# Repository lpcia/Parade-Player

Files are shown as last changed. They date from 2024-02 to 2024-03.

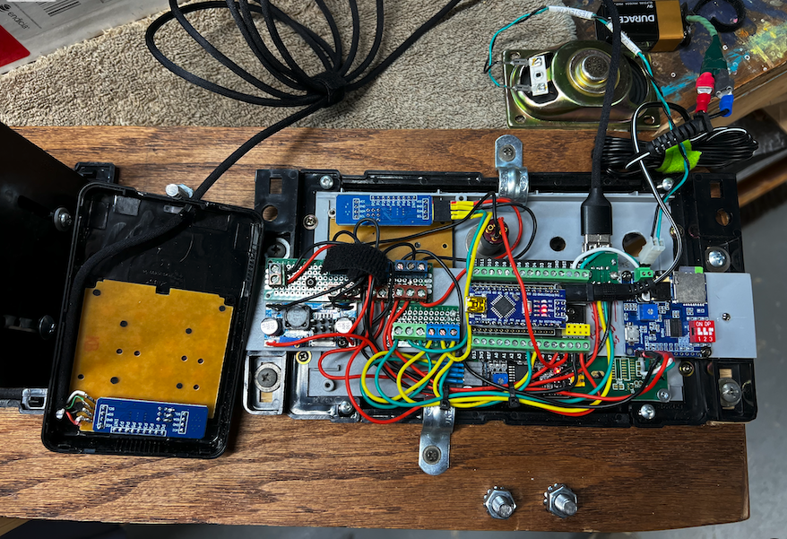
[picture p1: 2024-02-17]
Media/Version 2 almost complete (Note test speaker and Battery).png

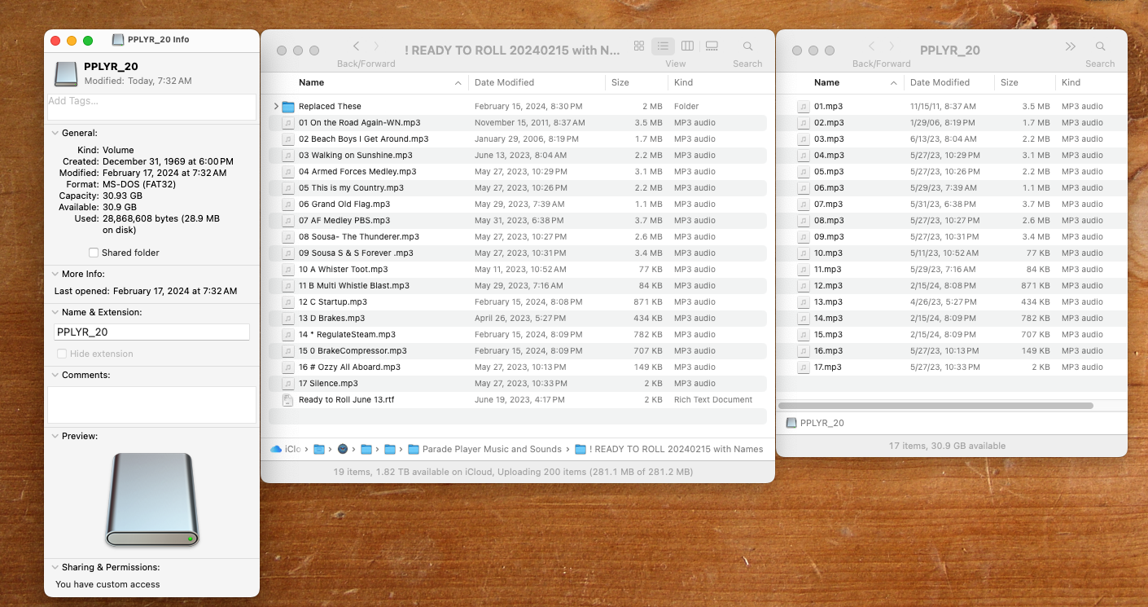
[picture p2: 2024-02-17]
Sound File Naming Example.png

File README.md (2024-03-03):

# Parade Player
Arduino based DY-???? / DYPlayer MP3 Player with I2CKeyPad input, and a HD44780 LCD Display.  Designed for parade floats.
This version works with an automobile head-unit using just the aux port.  Of course we have large weatherproof speakers on our "float".  We didn't need an external amplifier in our case.  Those speakers are loud enough!

## Concept

This is an Arduino Project that lets people interact with audio (in this case), lighting, and anamatronics.

## Background
I belong to a G Scale model railroad club that sets up large displays at train shows and local civic events such as a Christmas display at our city museum.  I wanted to make a display / decoration of an old service station that visitors could interact with to play sounds, start animatronics, or turn on lights by pressing a button on a (wired) remote keypad.

I had been toying around with various keypads / mp3 player circuit boards, etc. when a veterans group I belong to finally decided to reactivate an old self-propelled locomotive parade float that had been sitting in a garage for 15 years.  The vehicle is a modified 1938 Nash Lafayette built at the Nash plant here in Kenosha, WI.  In order to modernize her, We had to remove 200+ pounds of compressors, tanks, air lines and 80 years of old wiring and automotive electronics from the 1970's.  Instead of using air, I decided to use electronics to play music and sounds and re-engineered my idea into this Parade Locomotive Player.

## Operations
The MP3 Player is powered by the vehicle's 12 volt battery via a buck converter.  It is connected to the vehicle radio/ head-unit via the aux port.  In my case, I can play CD's and the Radio through the fender mounted speakers using the radio's controls.  Volume is also controlled by the radio.  

To play sounds, simply push a button on the keypad, and i'n my case a wired remote.  We added a remote because the driver cannot see the right front because of bells and smoke stacks, so a co-enginneer is required.  Even for them, pressing one of the buttons on the unit took their eyes off the road, so the remote was added.  It is simply a second keyboard / PCF8574 Remote 8-Bit I/O Expander for I2C Bus.  I wired it with a ten foot, tough old USB cable and used the existing USB connector (Probably a bad idea, but it works!).  Oddly the wired remote works without changes to the code.  I thought I was going to have to change the I2C address, but it just worked.

## Etcetera
Check out the pictures of our locomotive in the Media folder or visit https://sewivets.org/Voiture410/ 

> If you would like to donate to this project or our Nurses Training Fund, please see details on the website.

Thanks to 
1. Chris Snijde for the awesome work he did to make using generic DY players easy to use.
    - https://github.com/SnijderC/dyplayer
3. Gavin Lyons for is work with HD44780_LCD_PCF8574.h
    - https://github.com/gavinlyonsrepo/HD44780_LCD_PCF8574
4. And of course Adafruit!
    - https://www.adafruit.com

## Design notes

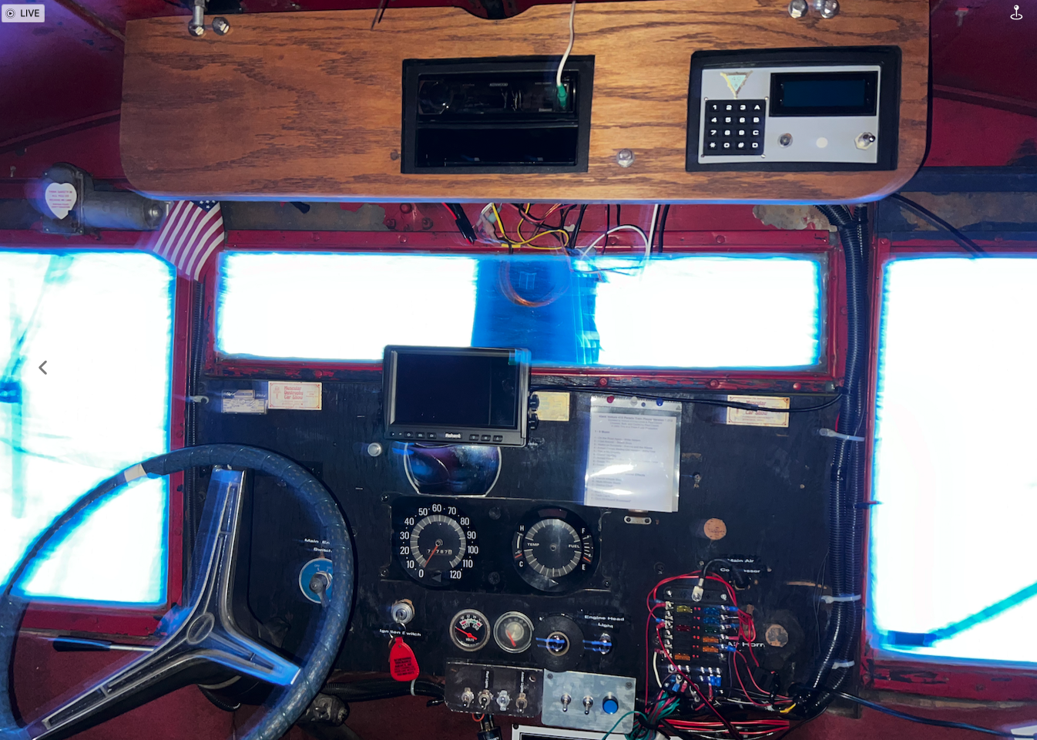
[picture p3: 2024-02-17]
Media/Cab_Nearly_Complete.png

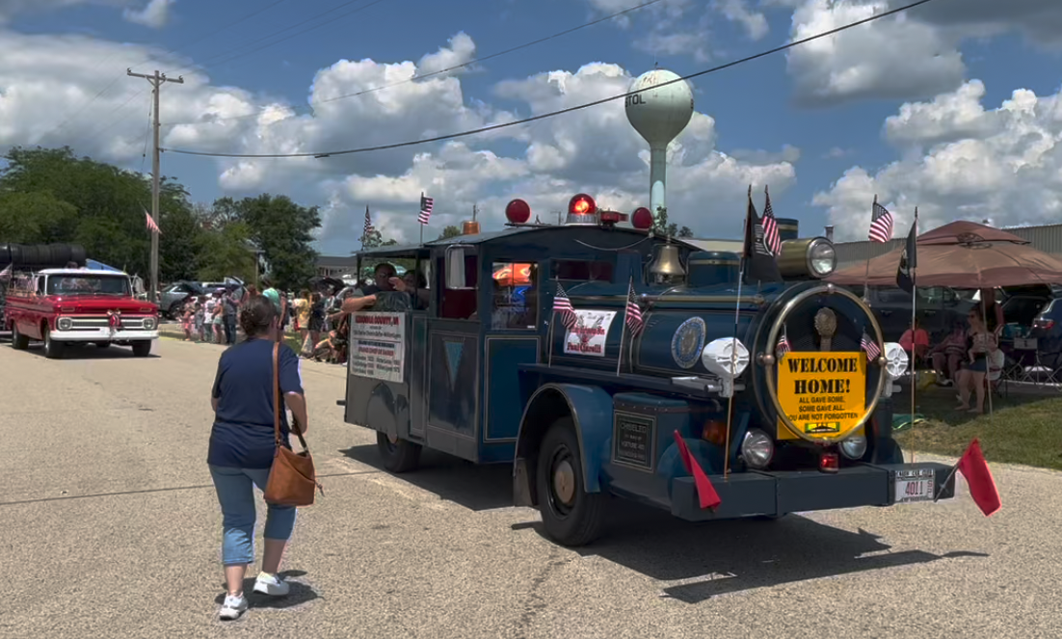
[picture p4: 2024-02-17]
Media/InTheParade.png

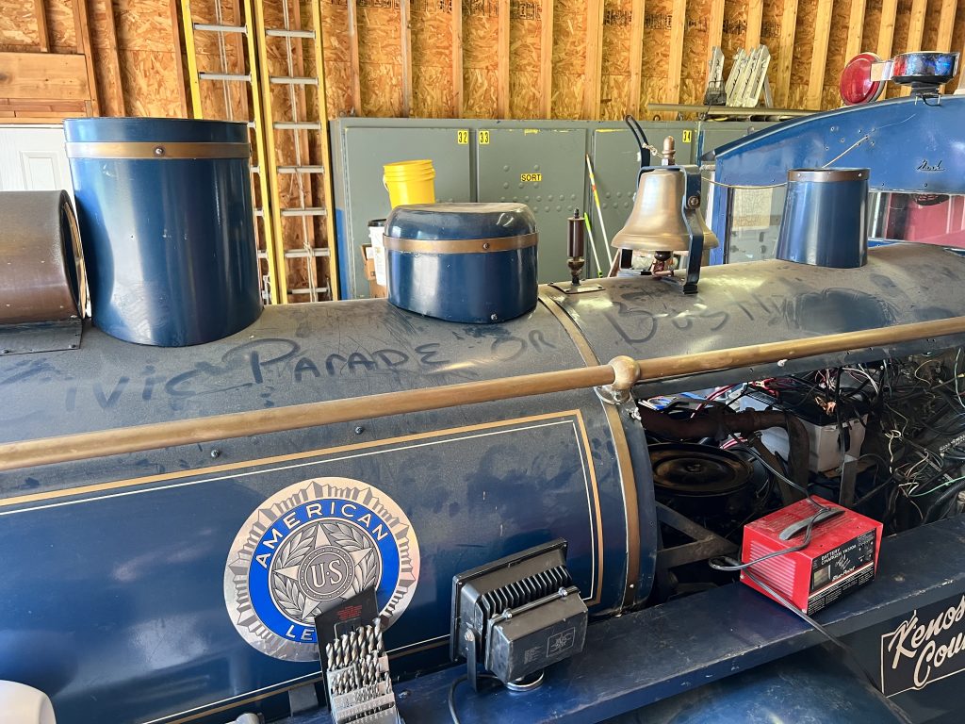
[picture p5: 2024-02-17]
Media/CivicParadeorBust.jpeg

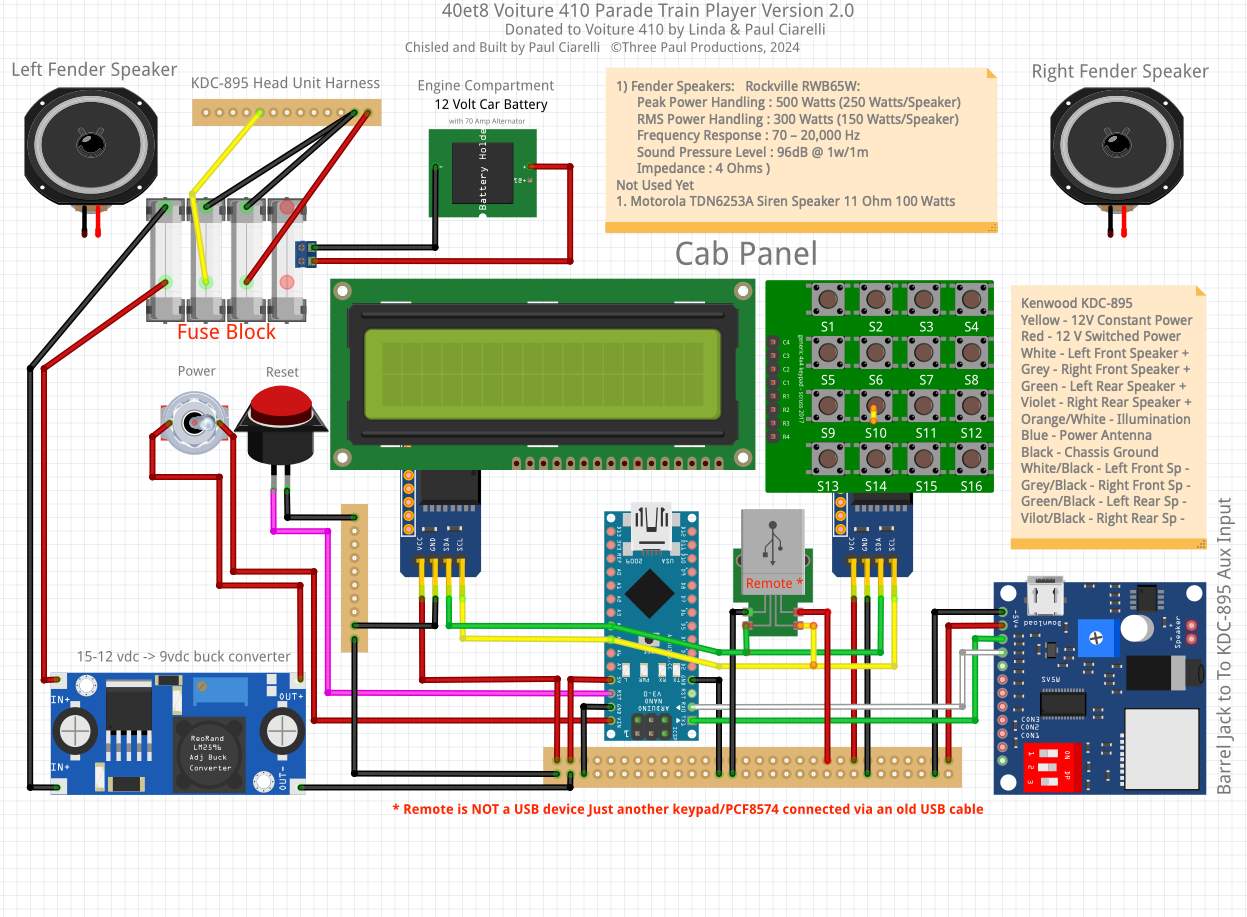
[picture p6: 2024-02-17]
Fritzing_Screenshot.png

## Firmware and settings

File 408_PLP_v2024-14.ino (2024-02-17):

/* 40et8 Voiture 410 Parade Train Player Version 2.2
   Donated to Voiture 410 by Linda & Paul Ciarelli
   Chiseled and Built by Paul Ciarelli   
   © 2003 This is a Three Pauls Production

Special Thanks to:
  Jim Holter for donating wiring / electrical parts.
  Tim Green & the "Green Machine" for helping with design and installation

See Documentation Tab for more information

Functions:  
  Print to LCD: 
  void blurt2Display(int8_t x, char *displayLine1, char *displayLine2, int delayTime) {}
    LCD Line 0 - 4
    Lines 1 - 4 as strings
    set a delay if needed
  Play a sound file:  
    void playSelection(int selNumber, int selDuration) {  
    Selection # and length in seconds -- delay required to stop some chop.
*/

// Preamble
// Section: Included library 
#include <Arduino.h>
#include "DYPlayerArduino.h"      // DY-SV5W
#include "HD44780_LCD_PCF8574.h"  // Thanks Gavin Lyons!  This was the one.
#include "I2CKeyPad.h"            // 4x4 Telephone Keypad

// Section: Globals / Initialization
// Init MP3 Player
  DY::Player player;  // Initialise the player, it defaults to using Serial.

// Init Display
  HD44780LCD myLCD( 4, 20, 0x27, &Wire); // instantiate an object
//                     12345678901234567890  
  char lcdLine1[21] = "40&8 V410 P. Player "; // Lines 1 and 2 will normally be static,
  char lcdLine2[21] = "Press Reset to Stop "; 
  char lcdLine3[21]; // Lines 3 and 4 will show current variables such as song selected.
  char lcdLine4[21]; 
  uint32_t selDelay = 300;
  uint32_t normDelay = 4000;

// Init keypad
  const uint8_t KEYPAD_ADDRESS = 0x20;
  I2CKeyPad keyPad(KEYPAD_ADDRESS);
  uint32_t start, stop;
  uint32_t lastKeyPressed = 0;
  char iChar = " ";
// Section: Function Prototypes

// Section: Setup
// ====== ========= ========= ========= ========= ========= ========= =========|
void setup() {

  // Setup DY Player Setup
  player.begin();
  player.setVolume(30);        // 30 = 100% Volume
  player.setEq(DY::Eq::Rock);  // Rock is best-sounding for small speakers
  player.setCycleMode(DY::PlayMode::OneOff);

  // Play Silence
  player.playSpecifiedDevicePath(DY::Device::Sd, "/17.MP3");

  // Setup Display
  myLCD.PCF8574_LCDInit(myLCD.LCDCursorTypeOn);
  myLCD.PCF8574_LCDClearScreen();
  myLCD.PCF8574_LCDBackLightSet(true);
  //                12345678901234567890  
  strcpy(lcdLine1, "40&8 Voiture 410    ");
  strcpy(lcdLine2, "Parade Player v2.14 ");
  strcpy(lcdLine3, "(C) 2023 Three Paul ");
  strcpy(lcdLine4, "Productions         ");
  blurt2Display(lcdLine1, lcdLine2, lcdLine3, lcdLine4, normDelay);
  
  // Setup Keypad
  if (keyPad.begin() == false) {  //  In essence just run keyPad.begin()
    strcpy(lcdLine1, "Error               ");
    strcpy(lcdLine2, "No Comm w/Keyboard  ");
    strcpy(lcdLine3, "                    ");
    strcpy(lcdLine4, "                    ");
    blurt2Display(lcdLine1, lcdLine2, lcdLine3, lcdLine4, normDelay);
    while (1)
      ;
  }
  // Let's Go...   // Loop Instructions
    //              12345678901234567890  
  strcpy(lcdLine3, "Letter: Loco Sfx    ");
  strcpy(lcdLine4, "Number: Song        ");
  blurt2Display(lcdLine1, lcdLine2, lcdLine3, lcdLine4, selDelay);

}  // setup

// ====== ========= ========= ========= ========= ========= ========= =========|
void loop() {

  uint32_t now = millis();
  // Select Keyboard Type --  N = NO_KEY, F = FAILED Note NO_KEY is MIA ? !
      char plpKey[19] = "147*2580369#ABCDNF";  // 16 Key Black Telephone Kepad
    //char plpKey[19] = "123A456B789C*0#DNF";  // 16 Key Membrane Keypad Red/Blue
  
  // set lcd lines one and two back to sandard and keep 3 & 4 from Growing past 20 Char!
  strcpy(lcdLine1, "40&8 Voiture 410    ");
  strcpy(lcdLine2, "Parade Player v2.14 ");
  strcpy(lcdLine3, "Press Reset to Stop ");
  strcpy(lcdLine4, "                    ");

  // Reset button (grounds the RST pin)
  // Press to stop music, and (not coincidentally) clear Heap Fragmentation

  if (now - lastKeyPressed >= 100) {
    lastKeyPressed = now;
    start = micros();
    uint8_t index = keyPad.getKey();
    iChar = plpKey[index];
    //                12345678901234567890
    strcpy(lcdLine3, "Selection:" );   // + the selection number
    strcpy(lcdLine4," " ); // + something!
    stop = micros();

    if (index != 16) {  // NO_KEY is not a thing!
      blurt2Display(lcdLine1, lcdLine2, lcdLine3, lcdLine4, selDelay);
      delay(100); 
      
      switch (iChar) {
        // Control keys
        // 0 - 9 are songs / music
        //                                  12345678901234567890
        case '1': playSelection("/01.MP3", "On the Road Again WN", selDelay); break;
        case '2': playSelection("/02.MP3", "I Get Around B Boys ", selDelay); break;
        case '3': playSelection("/03.MP3", "Walkn on Sunshine KW", selDelay); break;
        case '4': playSelection("/04.MP3", "Armed Forces Medley ", selDelay); break;
        case '5': playSelection("/05.MP3", "This is My Country  ", selDelay); break;
        case '6': playSelection("/06.MP3", "Grand Old Flag      ", selDelay); break;
        case '7': playSelection("/07.MP3", "New AF Medley PBS   ", selDelay); break;
        case '8': playSelection("/08.MP3", "Sousa The Thunderer ", selDelay); break;
        case '9': playSelection("/09.MP3", "Sousa S & S Forever ", selDelay); break;

        // A - D /  0, *, # are Train Sound Effects
        case 'A': playSelection("/10.MP3", "French Whistle Blast", selDelay); break;
        case 'B': playSelection("/11.MP3", "Multi-Whistle Blasts", selDelay); break;
        case 'C': playSelection("/12.MP3", "Startup Chuff       ", selDelay); break;
        case 'D': playSelection("/13.MP3", "Brakes              ", selDelay); break;
        case '*': playSelection("/14.MP3", "Regulate Steam      ", selDelay); break;
        case '0': playSelection("/15.MP3", "Brake Compressor    ", selDelay); break;
        case '#': playSelection("/16.MP3", "Ozzy All Aboard!    ", selDelay); break;

        default:;
      }
    }
  }
}  // End main loop
// ====== ========= ========= ========= ========= ========= ========= =========|
// Funcitions
// Send data for all 4 display lines
void blurt2Display(char *displayLine1, char *displayLine2, 
                   char *displayLine3, char *displayLine4, int delayTime) {
//  lcd.home(); lcd.clear();
  myLCD.PCF8574_LCDClearScreen();
	myLCD.PCF8574_LCDGOTO(myLCD.LCDLineNumberOne, 0);   myLCD.PCF8574_LCDSendString(displayLine1);
	myLCD.PCF8574_LCDGOTO(myLCD.LCDLineNumberTwo, 0);   myLCD.PCF8574_LCDSendString(displayLine2);
  myLCD.PCF8574_LCDGOTO(myLCD.LCDLineNumberThree, 0);	myLCD.PCF8574_LCDSendString(displayLine3);
  myLCD.PCF8574_LCDGOTO(myLCD.LCDLineNumberFour, 0);  myLCD.PCF8574_LCDSendString(displayLine4);
  delay(delayTime);
}
// Play:  supply Selection #, Nanme for Display, and duration in seconds
void playSelection(char *filePath, char *displayLine4, int selDuration) { 
// Update Display line 4 with the name of the selection
  myLCD.PCF8574_LCDGOTO(myLCD.LCDLineNumberFour, 0);  myLCD.PCF8574_LCDSendString(displayLine4);
  player.playSpecifiedDevicePath(DY::Device::Sd, filePath);  // play the selection
  delay(selDuration); // requred delay 
}

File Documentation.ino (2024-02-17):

/*
Hardware:  See Fritzing Schematic for wiring. (on Github....)

  (1) Arduino nano
  (1) 20x4 Display with I2C Interface Module
  (2) 16 Push button telephone keypads /  PCF8574  (*2 if you need a wired Remote)
  (1) LM2596 DC-DC Buck Converter (Input 5.2 to 35V Output 1.25 to 30V)  CAREFUL, no Reverse Polarity Circuit
  (1) Rocker Switch  PS1   Master Power Switch (Eventually this will turn off the AMP as well) 
  (1) DY-SV5W MP3 Player (Any that works https://github.com/SnijderC/dyplayer/tree/main
  
  Variable
  (1) Kenwood KDC-895 Head Unit (Radio/CD/Line In)  Just a headunit with an line in
  (2) Rockville RWB65W Marine Speakers

  *  Include an arduino reset button (Heap Fragmentation)  (Ground RST)
  Can use vehicle 12 volts (use FUSED hot wire), but use a dedicated batter for stable power.
    The vehicle this was designed for is very old and I don't trust the electrics.
// ====== ========= ========= ========= ========= ========= ========= =========|

Sources:  (SIM Card contains all code and documents)
Datasheet: https://grobotronics.com/images/companies/1/datasheets/DY-SV5W%20Voice%20Playback%20ModuleDatasheet.pdf
Example Implementation:  https://github.com/SnijderC/dyplayer
16-key keypad with an Arduino and a PCF8574 I/O expander module example (Borrowed heavly from this)
  https://curiousscientist.tech/blog/16-key-keypad-arduino-simplified

// ====== ========= ========= ========= ========= ========= ========= =========|
Sound File SD Card Instructions  ## Loading sound files

For normal playback of sound files, I recommend you name your files
sequentially and put them in the root directory of the drive unless you need
something more fancy. The numbering should be as follows:

00001.mp3
00002.mp3
00003.mp3
...

#### Important: files do not play in order of named sequence  <<<--------

The [`DY::DYPlayer::playSpecified`] function will **not** necessarily play the 
sound file named `00001.MP3` when asked to play sound file `1`. The module will 
look for the first sound file found in the filesystem. It's not using the file 
name, neither does it order by file name. 

To be sure the sound files play in the expected order:

1. Empty the storage device.
2. Make sure there aren't any trash files on the storage device.
3. Copy the files in the order they should be played (it helps to have them
   named sequentially, sort by name and copy the files, usually they will be
   copied in sequence order.
// ====== ========= ========= ========= ========= ========= ========= =========|


// ====== ========= ========= ========= ========= ========= ========= =========|
LCD Commands:
    lcd.setBacklight(255)     lcd.noDisplay();          lcd.display();
    lcd.clear();              lcd.home();               lcd.print("Hello LCD")
    lcd.scrollDisplayLeft()   lcd.scrollDisplayRight()  lcd.setCursor(0,0)(0,1)
    ABCD = Loco Sfx           Numbers = Music           * = Stop Playing 
   FUTURE: # Bank 2 of Numbers (More Music)             # = Play Selection

*/
